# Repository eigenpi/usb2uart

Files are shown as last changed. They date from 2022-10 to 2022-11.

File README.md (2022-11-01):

# USB to UART Converter

## Short Description

Design files (KiCAD layout, Arduino testing program, and 3D printing files of 
enclosure in Fusion 360) of a USB to UART converter.

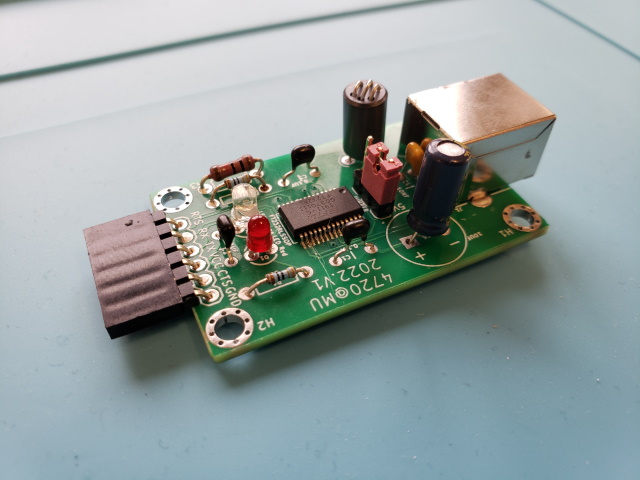
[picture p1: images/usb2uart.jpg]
Photo of converter


## Details

This repository contains all design files of a USB to UART converter.
The design uses the popular FT232R FTDI chip and its layout was created with
with KiCAD 6.0. The 3D CAD model was created with Autodesk Oct.2022, the free
educators/students version.

All the important design steps that you may want to follow to replicate this
project are described in several youtube videos. This project was split in these 
steps on purpose in order to help students learn for the first time KiCAD layout, 
how to reflow, solder, test, and print a 3D enclosure.

1. [Part 1: Introduction and Objectives](https://www.youtube.com/watch?v=YGBzahBK7fY)

2. [Part 2: Install Software and Design Considerations](https://www.youtube.com/watch?v=YuMDFhPcvQs)

3. [Part 3: Schematic Entry (or Capture)](https://www.youtube.com/watch?v=v7kIc4Z1D-g)

4. [Part 4: Footprint Assignment and Netlist Generation](https://www.youtube.com/watch?v=86rWFbxiwfI)

5. [Part 5: Placement](https://www.youtube.com/watch?v=sIsJZZ_kQxs)

6. [Part 6: Routing](https://www.youtube.com/watch?v=J2sLzAaGzOM)

7. [Part 7: Soldering](https://www.youtube.com/watch?v=Kl9dPHJpTGs)

8. [Part 8: Testing and Programming an Arduino Pro Mini](https://www.youtube.com/watch?v=vrjB3BWouZs)

9. [Part 9: 3D Printed Enclosure Designed in Autodesk Fusion 360](https://youtu.be/6EWKOvSFG48)

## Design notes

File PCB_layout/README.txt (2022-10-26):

usb2uart/ project folder created with KiCAD 6.0

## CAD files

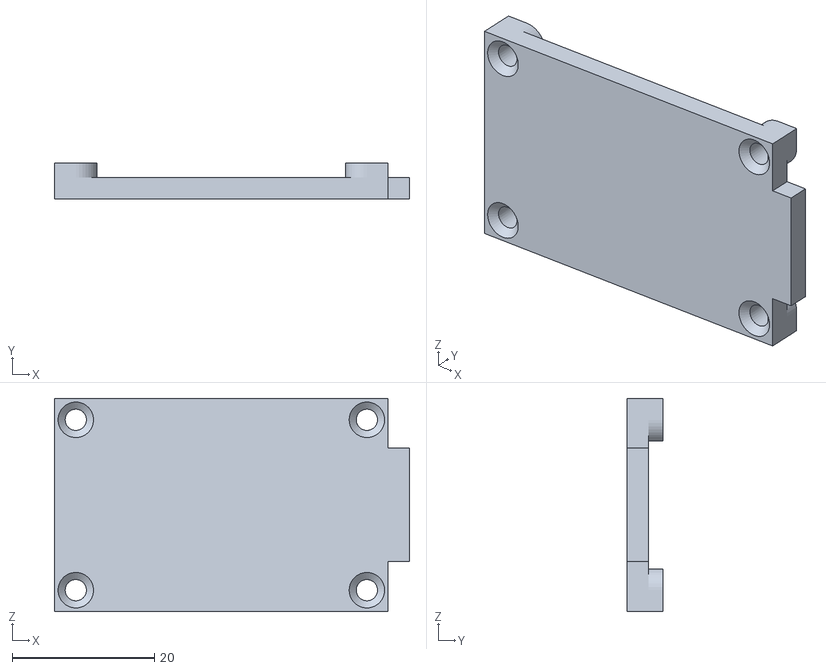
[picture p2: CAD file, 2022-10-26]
3D_printing_enclosure/usb2uart_lid.stl
50.0 x 5.00 x 30.0

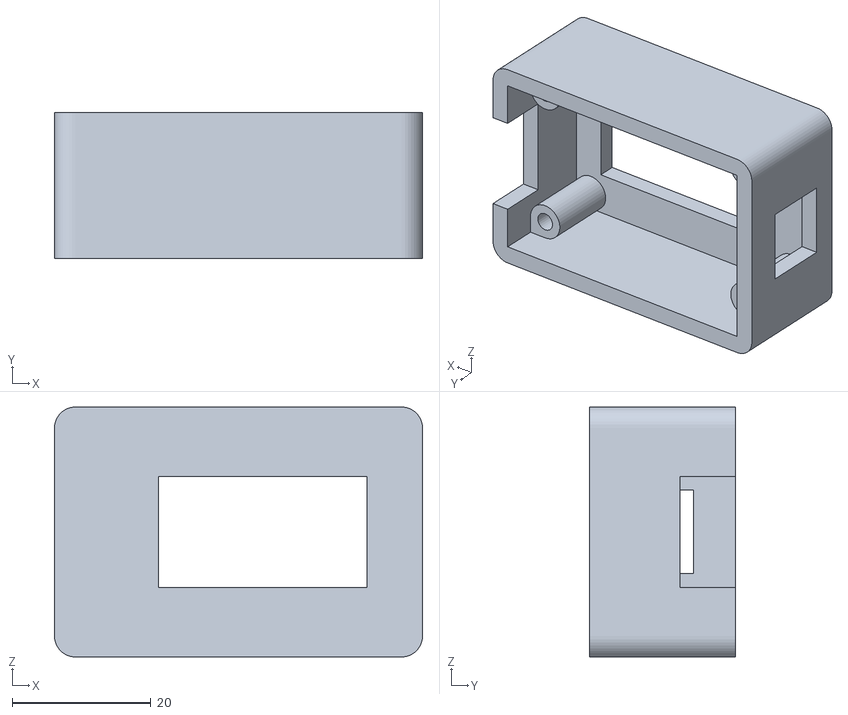
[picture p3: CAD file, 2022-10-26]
3D_printing_enclosure/usb2uart.stl
53.0 x 21.0 x 36.0

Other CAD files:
3D_printing_enclosure/usb2uart.f3d
3D_printing_enclosure/usb2uart_lid.f3d

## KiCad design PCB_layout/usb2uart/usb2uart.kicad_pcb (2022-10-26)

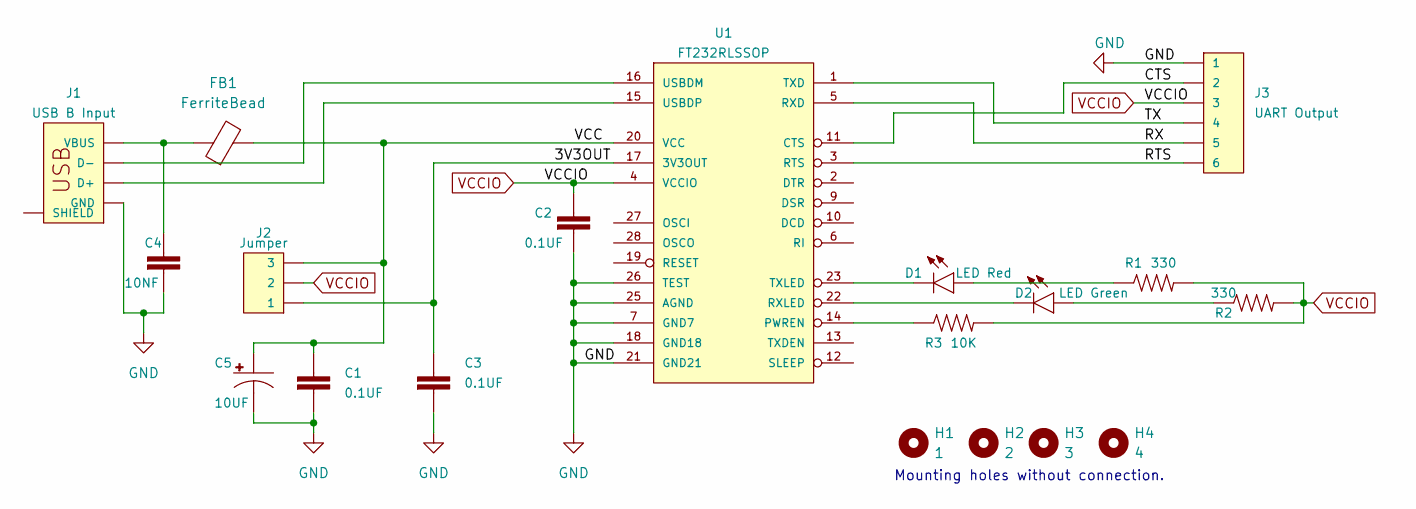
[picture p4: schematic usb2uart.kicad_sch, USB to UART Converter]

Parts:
C1, C2, C3: 0.1UF; CAP-PTH-5MM
C4: 10NF; CAP-PTH-5MM
C5: 10UF; CPOL-RADIAL-5MM-10MM
D1: LED Red; LED_3MM
D2: LED Green; LED_3MM
FB1: FerriteBead; LairdTech_28C0236-0JW-10
H1: 1; STANDOFF_GROUNDING
H2: 2; STANDOFF_GROUNDING
H3: 3; STANDOFF_GROUNDING
H4: 4; STANDOFF_GROUNDING
J1: USB B Input; USB-B-PTH
J2: Jumper; 1X03
J3: UART Output; 1X06
R1, R2: 330; AXIAL-0.3
R3: 10K; AXIAL-0.3-KIT
U1: FT232RLSSOP; SSOP28DB

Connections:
/3V3OUT: C3.1, J2.1, U1.17 (3V3OUT)
/CTS: J3.2, U1.11 (CTS)
/RTS: J3.6, U1.3 (RTS)
/RX: J3.5, U1.5 (RXD)
/TX: J3.4, U1.1 (TXD)
/VCC: C1.1, C5.+, FB1.2, J2.3, U1.20 (VCC)
GND: C1.2, C2.2, C3.2, C4.2, C5.-, J1.GND, J3.1, U1.7 (GND7), U1.18 (GND18), U1.21 (GND21), U1.25 (AGND), U1.26 (TEST)
unnamed: C4.1, FB1.1, J1.VBUS
unnamed: D1.A, R1.P$1 (1)
unnamed: D1.K (C), U1.23 (TXLED)
unnamed: D2.A, R2.P$1 (1)
unnamed: D2.K (C), U1.22 (RXLED)
unnamed: R3.P$1 (1), U1.14 (PWREN)
unnamed: J1.D+, U1.15 (USBDP)
unnamed: J1.D-, U1.16 (USBDM)
VCCIO: C2.1, J2.2, J3.3, R1.P$2 (2), R2.P$2 (2), R3.P$2 (2), U1.4 (VCCIO)

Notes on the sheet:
Mounting holes without connection.

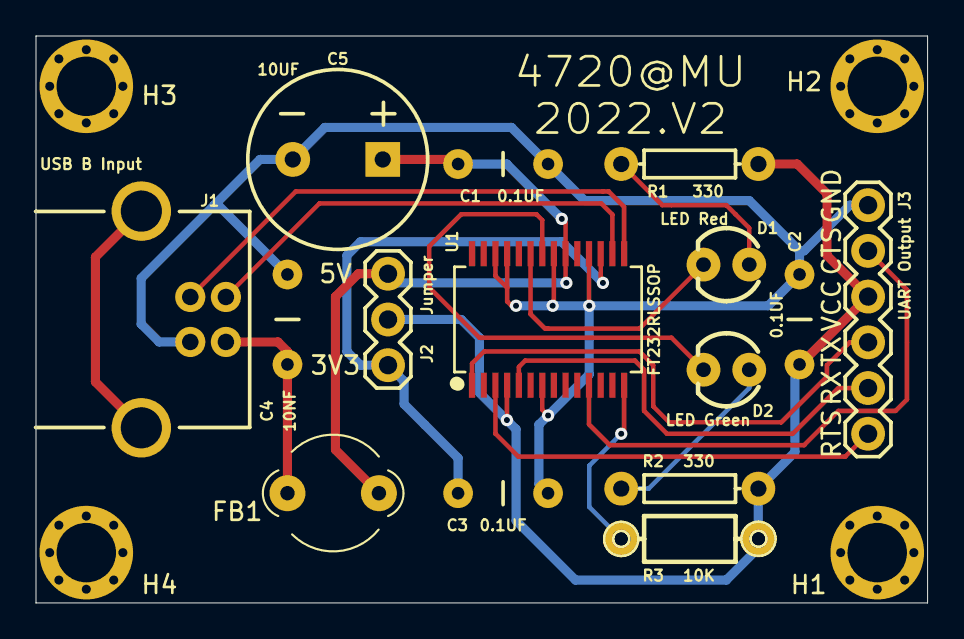
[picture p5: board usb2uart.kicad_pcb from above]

Board: 2 copper layers, 49.5 x 31.5 mm, 19 parts (0 on the bottom side), 16 nets.

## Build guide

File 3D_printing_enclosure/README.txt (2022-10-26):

These are 3D models of an enclosure for the USB2UART programmer.
YOu really need only the .STL files to 3D print it.
These models were created with Autodesk Fusion 360 (Version 2.0.14567)

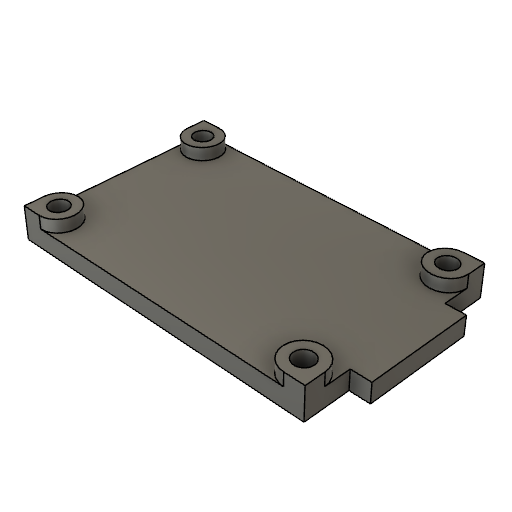
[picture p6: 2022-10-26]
3D_printing_enclosure/usb2uart_lid.png

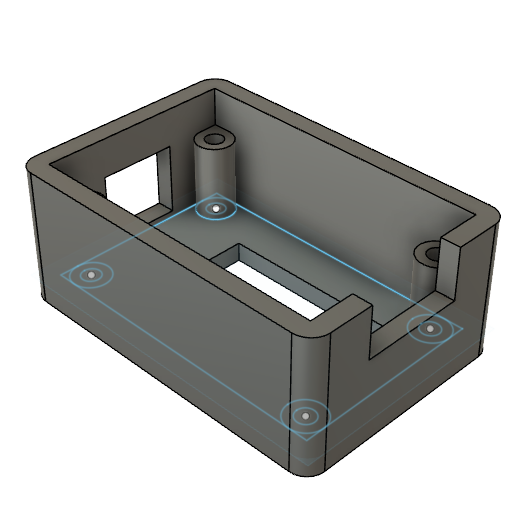
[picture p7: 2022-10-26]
3D_printing_enclosure/usb2uart.png

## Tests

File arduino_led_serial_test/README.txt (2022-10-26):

This is a very simple Arduino sketch that was used to test the programmer 
and to snoop/monitor the UART Serial bus in an experimental setup with an 
Arduino Pro Mini and a Rigol oscilloscope.

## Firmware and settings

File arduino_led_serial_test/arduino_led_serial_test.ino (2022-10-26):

void setup() {
  // initialize digital pin LED_BUILTIN as an output.
  pinMode(LED_BUILTIN, OUTPUT);
  // initialize Serial;
  Serial.begin(9600);
}

void loop() {
  /*---
  digitalWrite(LED_BUILTIN, HIGH);   
  delay(2000);                 
  digitalWrite(LED_BUILTIN, LOW); 
  delay(2000);
  ---*/  
                   
  // send "Cris" via serial to host pc;
  // ASCII Table at: https://www.rapidtables.com/code/text/ascii-table.html
  //
  //                               Dec   Hex   Binary  HTML  Char  Description
  Serial.print("C");  delay(5); // 67    43  01000011  &#67;   C   Capital C
  Serial.print("r");  delay(5); // 114   72  01110010  &#114;  r   Small r
  Serial.print("i");  delay(5); // 105   69  01101001  &#105;  i   Small i
  Serial.print("s");  delay(5); // 115   73  01110011  &#115;  s   Small s
  Serial.println();   delay(20);// 13    0D  00001101  &#13;   CR  Carriage Return
  //                            // 10    0A  00001010  &#10;   LF  Line Feed
}
